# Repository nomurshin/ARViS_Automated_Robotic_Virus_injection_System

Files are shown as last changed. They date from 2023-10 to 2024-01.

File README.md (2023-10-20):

# Welcome to the ARViS!

The goal of this repository is to help advance and disseminate automated injection technology to the neuroscience community. While the automated injection platform described here is not an off-the-shelf commercial solution, we have made efforts to make it as easy as possible for any neuroscience lab to build, use, and modify the platform.

The ARViS is designed to perform multiple injections onto the cortex of mice and non-human primates, but it can also be utilized for other animals and other regions in the brain. Some feature highlights are listed below.

# Feature Highlights
- ~50 μm accuracy
- \>100 sequential injections
- 20 sec traveling time per site
- Flexible setting of injection regions
- 7 x 14 mm wide-field imaging

# Please visit our [wiki](https://github.com/nomurshin/ARViS_prepublication/wiki)!
We've provided comprehensive introduction to help you navigate each part of the platform there.

# How to Install
All scripts of the ARViS platform are written as MATLAB scripts, except for SA-UNet and Autostitch.

1. Fork, clone, or copy the repository to your local computer.
2. [Download MATLAB R2021b](https://www.mathworks.com/products/matlab.html).
3. Download the related toolboxes listed below from the MATLAB Add-On Manager.
4. Download [SA-UNet](https://github.com/clguo/SA-UNet) and create a Python environment to execute it.
5. Download [Autostitch](http://matthewalunbrown.com/autostitch/autostitch.html).

# Dependencies

The environment specifications are as follows:

- **Operating System**: Windows 10 Pro Education
- **Processor**: Intel(R) Core(TM) i7-9700K CPU @ 3.60GHz   3.60 GHz
- **Graphics Card**: NVIDIA GeForce RTX 2070 SUPER
- **MATLAB Version**: MATLAB R2021b
  - Computer Vision Toolbox v.10.3
  - Curve Fitting Toolbox v.3.8
  - Image Acquisition Toolbox v.6.7
  - Image Processing Toolbox v.11.6
  - Optimization Toolbox v.9.4
  - Parallel Computing Toolbox v.7.7
  - Signal Processing Toolbox v.9.1
  - Global Optimization Toolbox v.4.6
  - MATLAB Support Package for USB Webcams v.21.2
  - Image Acquisition Toolbox Support Package for GenICam Interface v.21.2
- **Other Dependencies**:
  - [SA-UNet](https://github.com/clguo/SA-UNet) (refer to the original site for more information)
  - [Autostitch](http://matthewalunbrown.com/autostitch/autostitch.html) (refer to the original site for more information)

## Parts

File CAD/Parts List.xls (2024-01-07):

Cat. No, | Item | Manufacture | Product URL | Qty
H-820 | H-820 6-Axis Hexapod | PI | https://www.pi-southeast.asia/en/products/parallel-kinematic-hexapods/h-820-6-axis-positioner-with-controller-700825 | 1
scA1440-220um | Basler Ace acA1440-220um USB 3.0 Monochrome Camera | Basler | https://www.edmundoptics.jp/p/basler-ace-aca1440-220um-usb-30-monochrome-camera/40359/ | 2
acA4024-29uc | Basler Ace acA4024-29uc USB 3.0 Color Camera | Basler | https://www.edmundoptics.jp/p/basler-ace-aca4024-29uc-usb-30-color-camera/37368/ | 1
2000029679 | Tripod Mount ace | Basler | https://www.baslerweb.com/ja-jp/shop/tripod-mount-ace/?sort=name | 2
63-745 | 1X, 40mm WD CompactTL™ Telecentric Lens | Edmund optics | https://www.edmundoptics.jp/p/1x-40mm-wd-compacttl-telecentric-lens/18475/ | 2
54-675 | InfiniStix 0.5X, 94mm WD Video Lens | Infinity Photo-Optical Company | https://www.edmundoptics.jp/p/infinistix-05x-94mm-wd-video-lens/11346/ | 1
3-000-207 | Nanoject III Programmable Nanoliter Injector | Drummond Scientific Company | https://www.drummondsci.com/product/microinjection/nanoject-iii-programmable-nanoliter-injector/ | 1
HG-C1050-P | CMOS type Micro Laser Distance Sensor | Panasonic | https://www3.panasonic.biz/ac/j/search_num/index.jsp?c=detail&part_no=HG-C1050-P | 1
BBH1 | Breadboard Lifting Handles Reinforced Polymer (Set of 2) | Thorlabs | https://www.thorlabs.co.jp/newgrouppage9.cfm?objectgroup_id=2806 | 2
MB4575/M | Aluminum Breadboard 450 mm x 750 mm x 12.7 mm M6 Taps | Thorlabs | https://www.thorlabs.co.jp/newgrouppage9.cfm?objectgroup_id=159 | 1
MB4545/M | Aluminum Breadboard 450 mm x 450 mm x 12.7 mm M6 Taps | Thorlabs | https://www.thorlabs.co.jp/newgrouppage9.cfm?objectgroup_id=159 | 1
VB01B/M | 18" Vertical Bracket for Breadboards M6 Holes 1 Piece | Thorlabs | https://www.thorlabs.co.jp/newgrouppage9.cfm?objectgroup_id=223 | 2
AB90B/M | Slim Right-Angle Bracket with Counterbored & M6 Tapped Holes | Thorlabs | https://www.thorlabs.co.jp/newgrouppage9.cfm?objectgroup_id=223 | 2
RLA075/M | Dovetail Optical Rail 75 mm Metric | Thorlabs | https://www.thorlabs.co.jp/newgrouppage9.cfm?objectgroup_id=30 | 1
AM16T/M | 16° Angle Block M4 Tap M4 Post Mount | Thorlabs | https://www.thorlabs.co.jp/newgrouppage9.cfm?objectgroup_id=5585 | 2
VC1/M | Small V-Clamp with PM3/M Clamping Arm 0.75" Long Metric | Thorlabs | https://www.thorlabs.co.jp/newgrouppage9.cfm?objectgroup_id=1317 | 2
RCN | Rail Carrier Positioner for Dovetail Rails | Thorlabs | https://www.thorlabs.co.jp/newgrouppage9.cfm?objectgroup_id=12588 | 1
MTS50/M-Z8 | 50 mm (1.97") Motorized Translation Stage M4 and M3 Taps | Thorlabs | https://www.thorlabs.co.jp/newgrouppage9.cfm?objectgroup_id=3002 | 1
RC1 | Dovetail Rail Carrier 1.00" x 1.00" (25.4 mm x 25.4 mm) 1/4" (M6) Counterbore | Thorlabs | https://www.thorlabs.co.jp/newgrouppage9.cfm?objectgroup_id=8295 | 1
RBB150A/M | Ø150 mm Rotating Breadboard M6 Taps | Thorlabs | https://www.thorlabs.co.jp/newgrouppage9.cfm?objectgroup_id=5087 | 1
UPH100/M | Ø12.7 mm Universal Post Holder Spring-Loaded Locking Thumbscrew L = 100 mm | Thorlabs | https://www.thorlabs.co.jp/newgrouppage9.cfm?objectgroup_id=1982 | 2
TR150/M-JP | Ø12 mm Optical Post SS M4 Setscrew M6 Tap L = 150 mm | Thorlabs | https://www.thorlabs.co.jp/newgrouppage9.cfm?objectgroup_id=1266 | 2

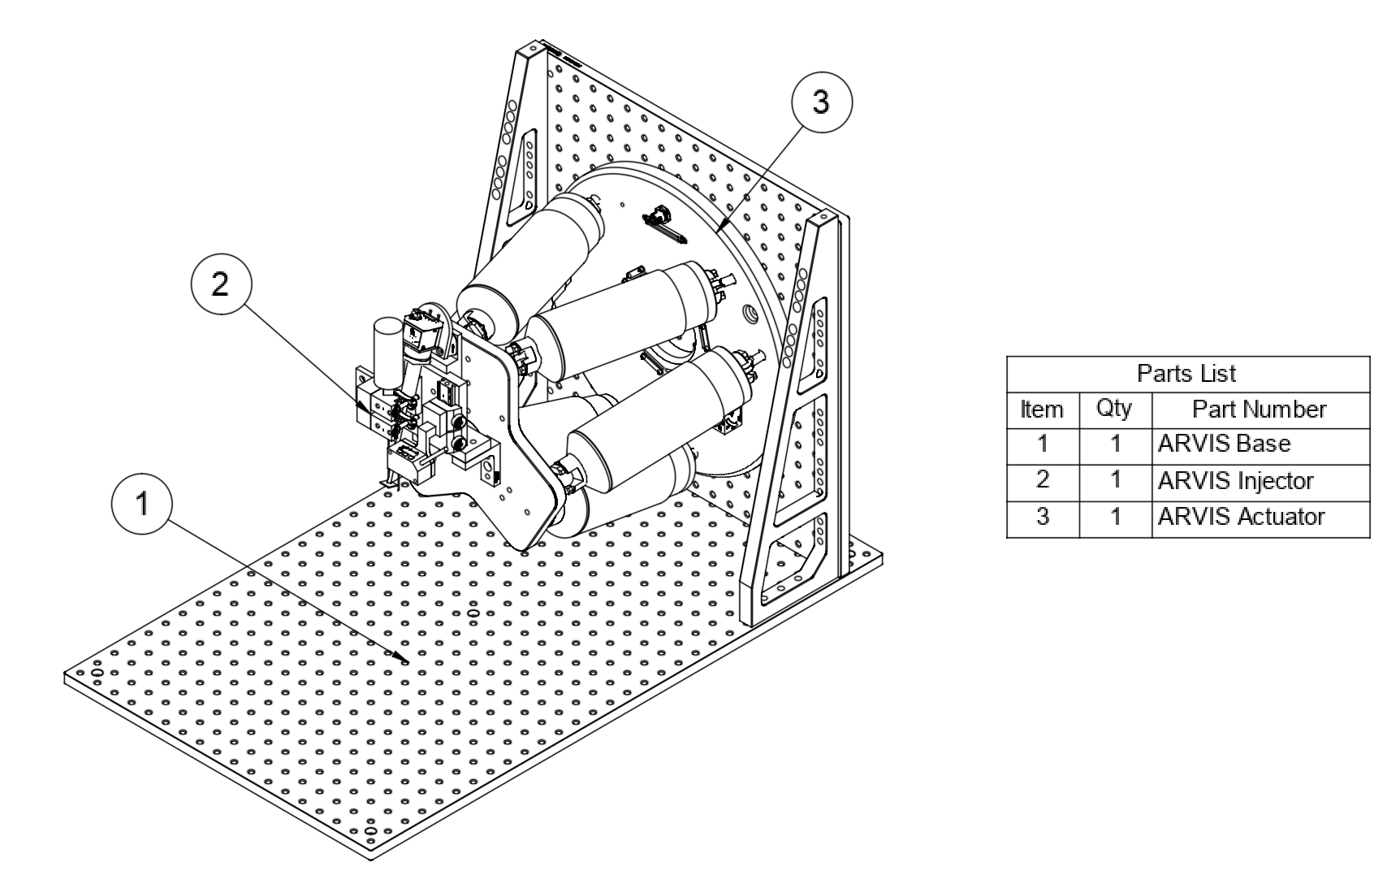
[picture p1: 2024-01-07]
docs/img/ARViS full components.png

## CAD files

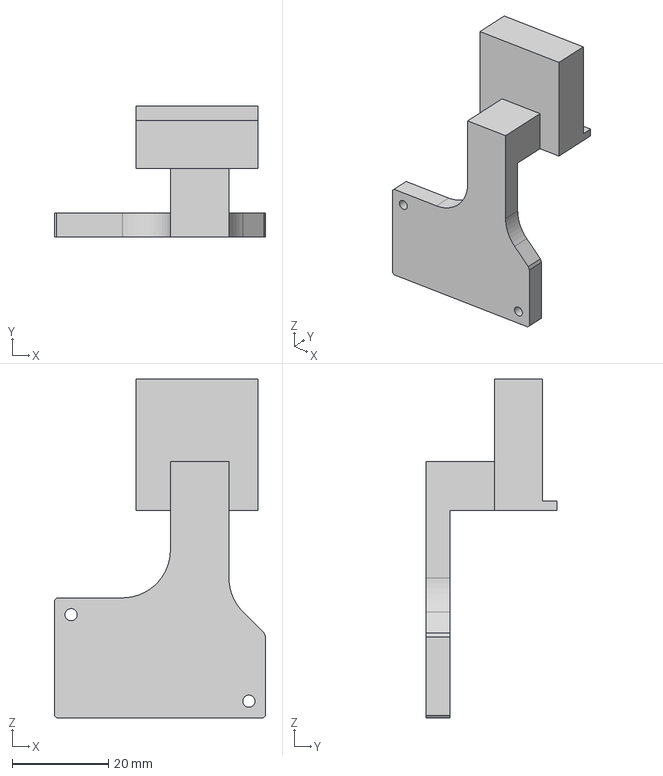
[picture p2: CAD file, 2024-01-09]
CAD/custom parts/HG-C mount.step
44.0 x 27.2 x 70.5 mm

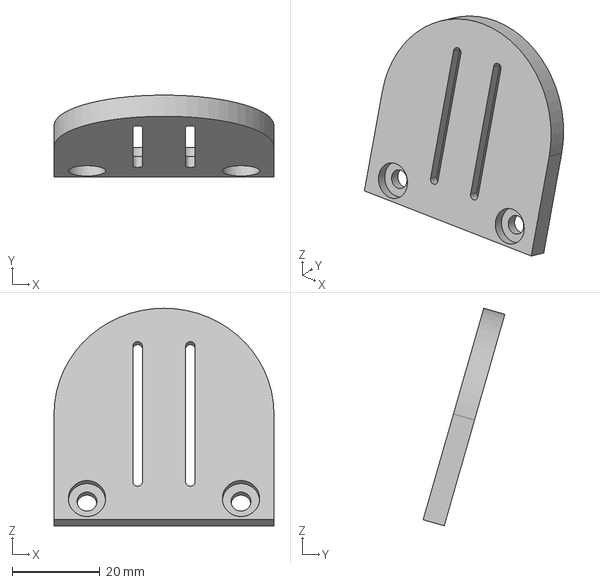
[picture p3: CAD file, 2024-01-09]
CAD/custom parts/Injector mount basler mount.step
50.0 x 18.6 x 49.4 mm

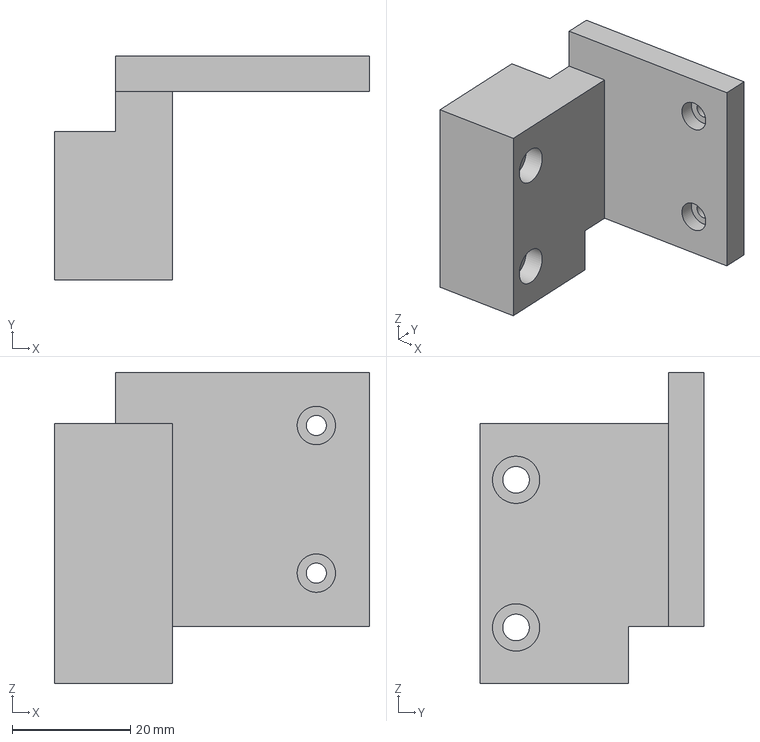
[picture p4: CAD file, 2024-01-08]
CAD/custom parts/Injector z-stage mout connector.step
53.3 x 37.9 x 52.7 mm

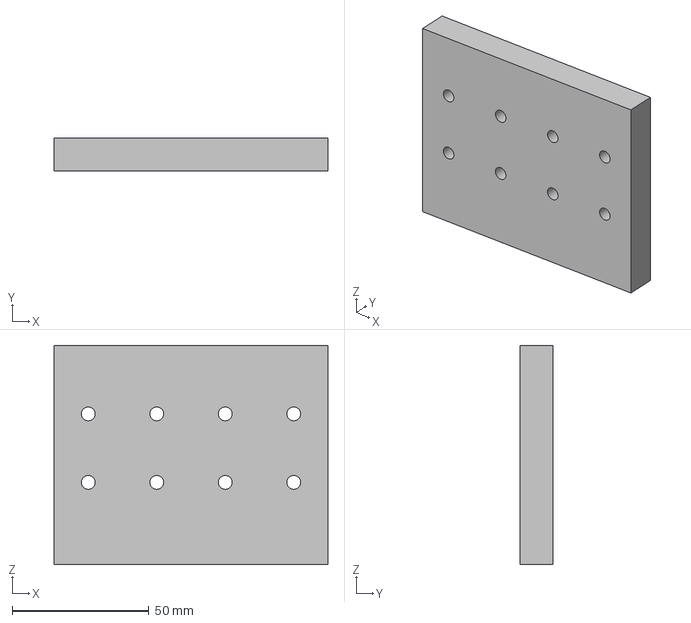
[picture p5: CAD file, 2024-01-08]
CAD/custom parts/Injector mount base B.step
100.0 x 12.0 x 80.0 mm

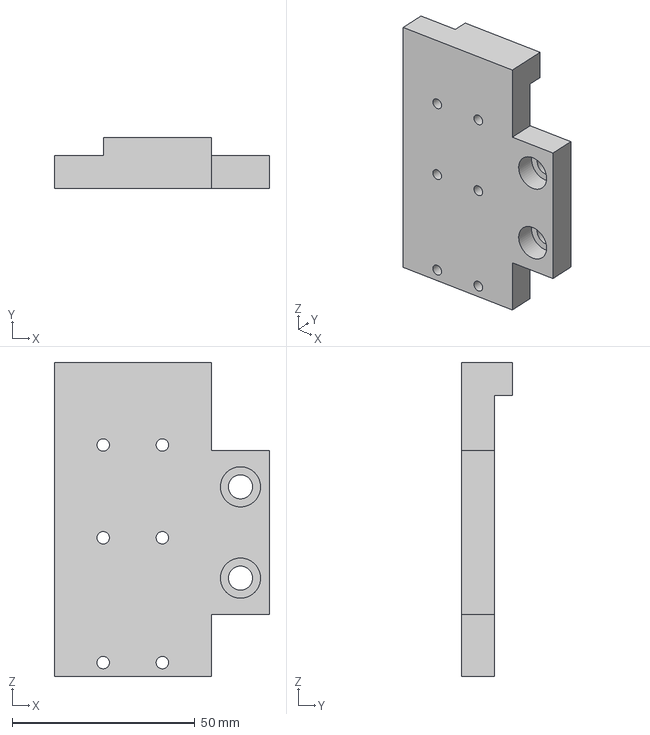
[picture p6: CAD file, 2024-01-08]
CAD/custom parts/z-stage mount.step
59.0 x 14.0 x 86.0 mm

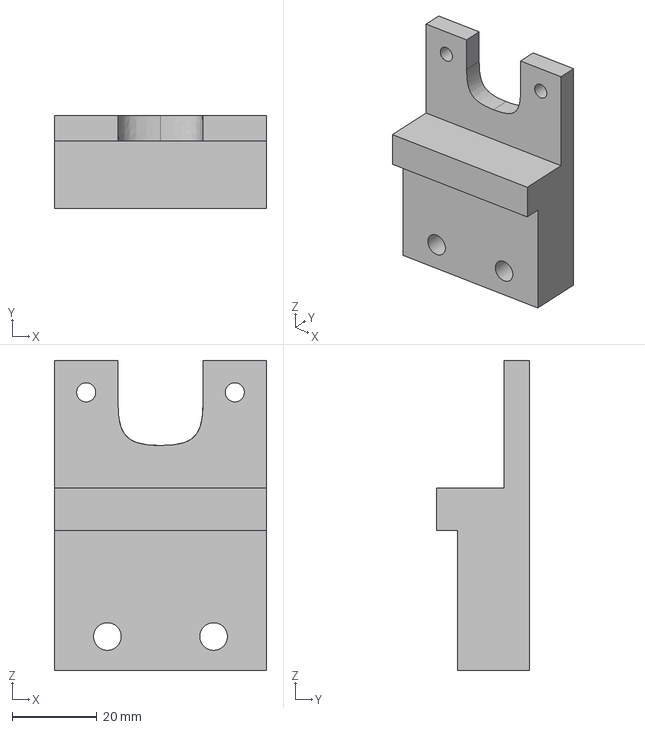
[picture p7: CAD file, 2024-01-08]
CAD/custom parts/Injector mount basler connector.step
50.0 x 22.0 x 73.0 mm

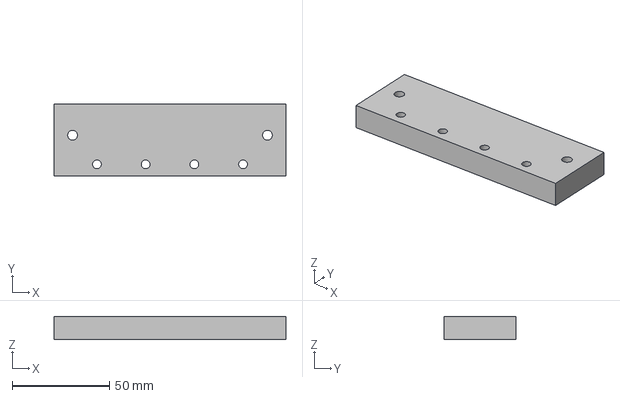
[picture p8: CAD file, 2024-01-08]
CAD/custom parts/Injector mount base A.step
119.1 x 37.0 x 12.0 mm

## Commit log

2023-10-20 Create CAD directory
2023-10-20 Add CAD of ARVIS
2023-10-20 Add custom parts files via upload
    [HG-C mount.step, Injector mount base_Injector mount base A.step, Injector mount base_Injector mount base B.step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]
2025-10-14 Uploaded the missing training images (41–46).
    These correspond to:
    - 41_manual1.png
    - 42_manual1.png
    - 43_manual1.png
    - 44_manual1.png
    - 45_manual1.png
    - 46_manual1.png
    Related to issue #1
